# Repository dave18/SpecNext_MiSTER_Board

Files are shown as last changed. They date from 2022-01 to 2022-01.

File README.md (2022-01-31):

# SpecNext_MiSTER_Board
An extension board to provide Spectrum Next functionality to MiSTER

A MiSTer hat board MiSTER based on the offical schematics to (hopefully) allow better compatibility with the Spectrum Next core, including future updates.

It adds
* SRAM - up to 2 MB as per the next using 4 x as7c34096a-10 
* VGA out (using same resistor values from Next schematic)
* Mic/Ear port
* Audio out
* Two DB9 joystick ports
* NMI/Drive/Reset buttons
* J13 header to add physical SD Card support

Core code is based on the official MiSTer Spectrum Next Core with the following changes
* Direct VGA option - will bypass MiSTer framework and send direct video signal to VGA out (note - once this option is selected the OSD will no longer be visible over VGA until option is disabled (OSD is still visible through HDMI/DVI)
* Option to set each joystick to either MiSTer input or directly from the DSub 9 inputs
* Tape loading will automatically switch between virtual tape if loaded or from the Ear port if not
* SD Card interface will use virtual cards if loaded, else will use the J13 signals (useful if you have an Active Consult drive to plug in)

Changelog

Board V1.0 (Eagle files V3a)







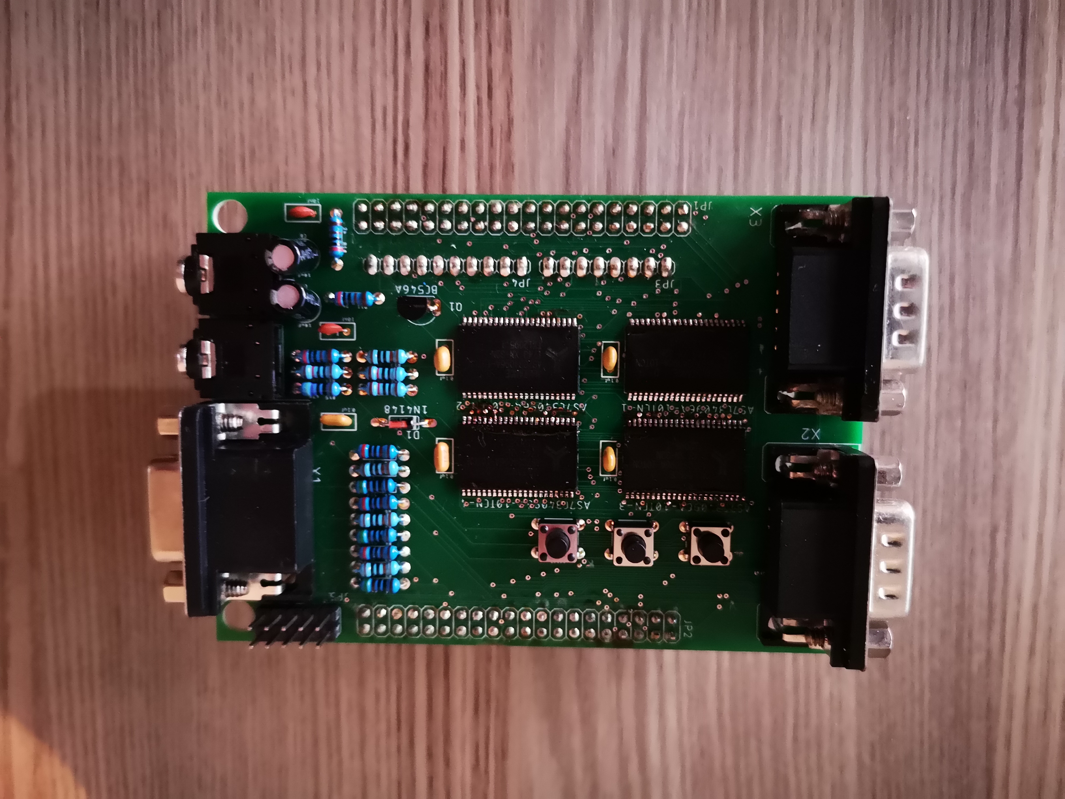
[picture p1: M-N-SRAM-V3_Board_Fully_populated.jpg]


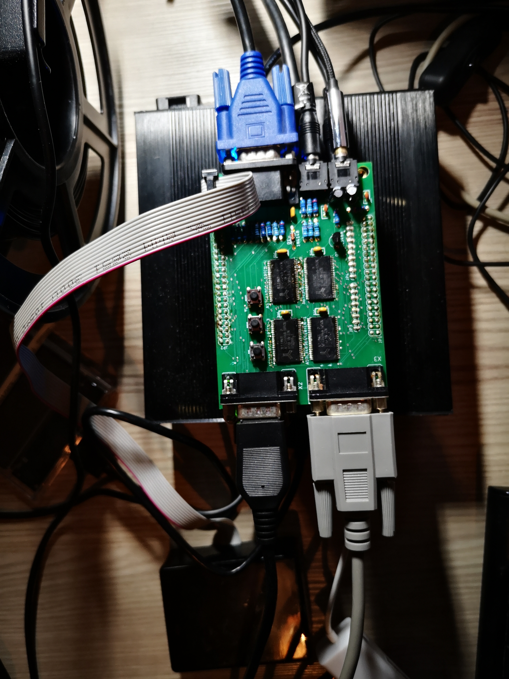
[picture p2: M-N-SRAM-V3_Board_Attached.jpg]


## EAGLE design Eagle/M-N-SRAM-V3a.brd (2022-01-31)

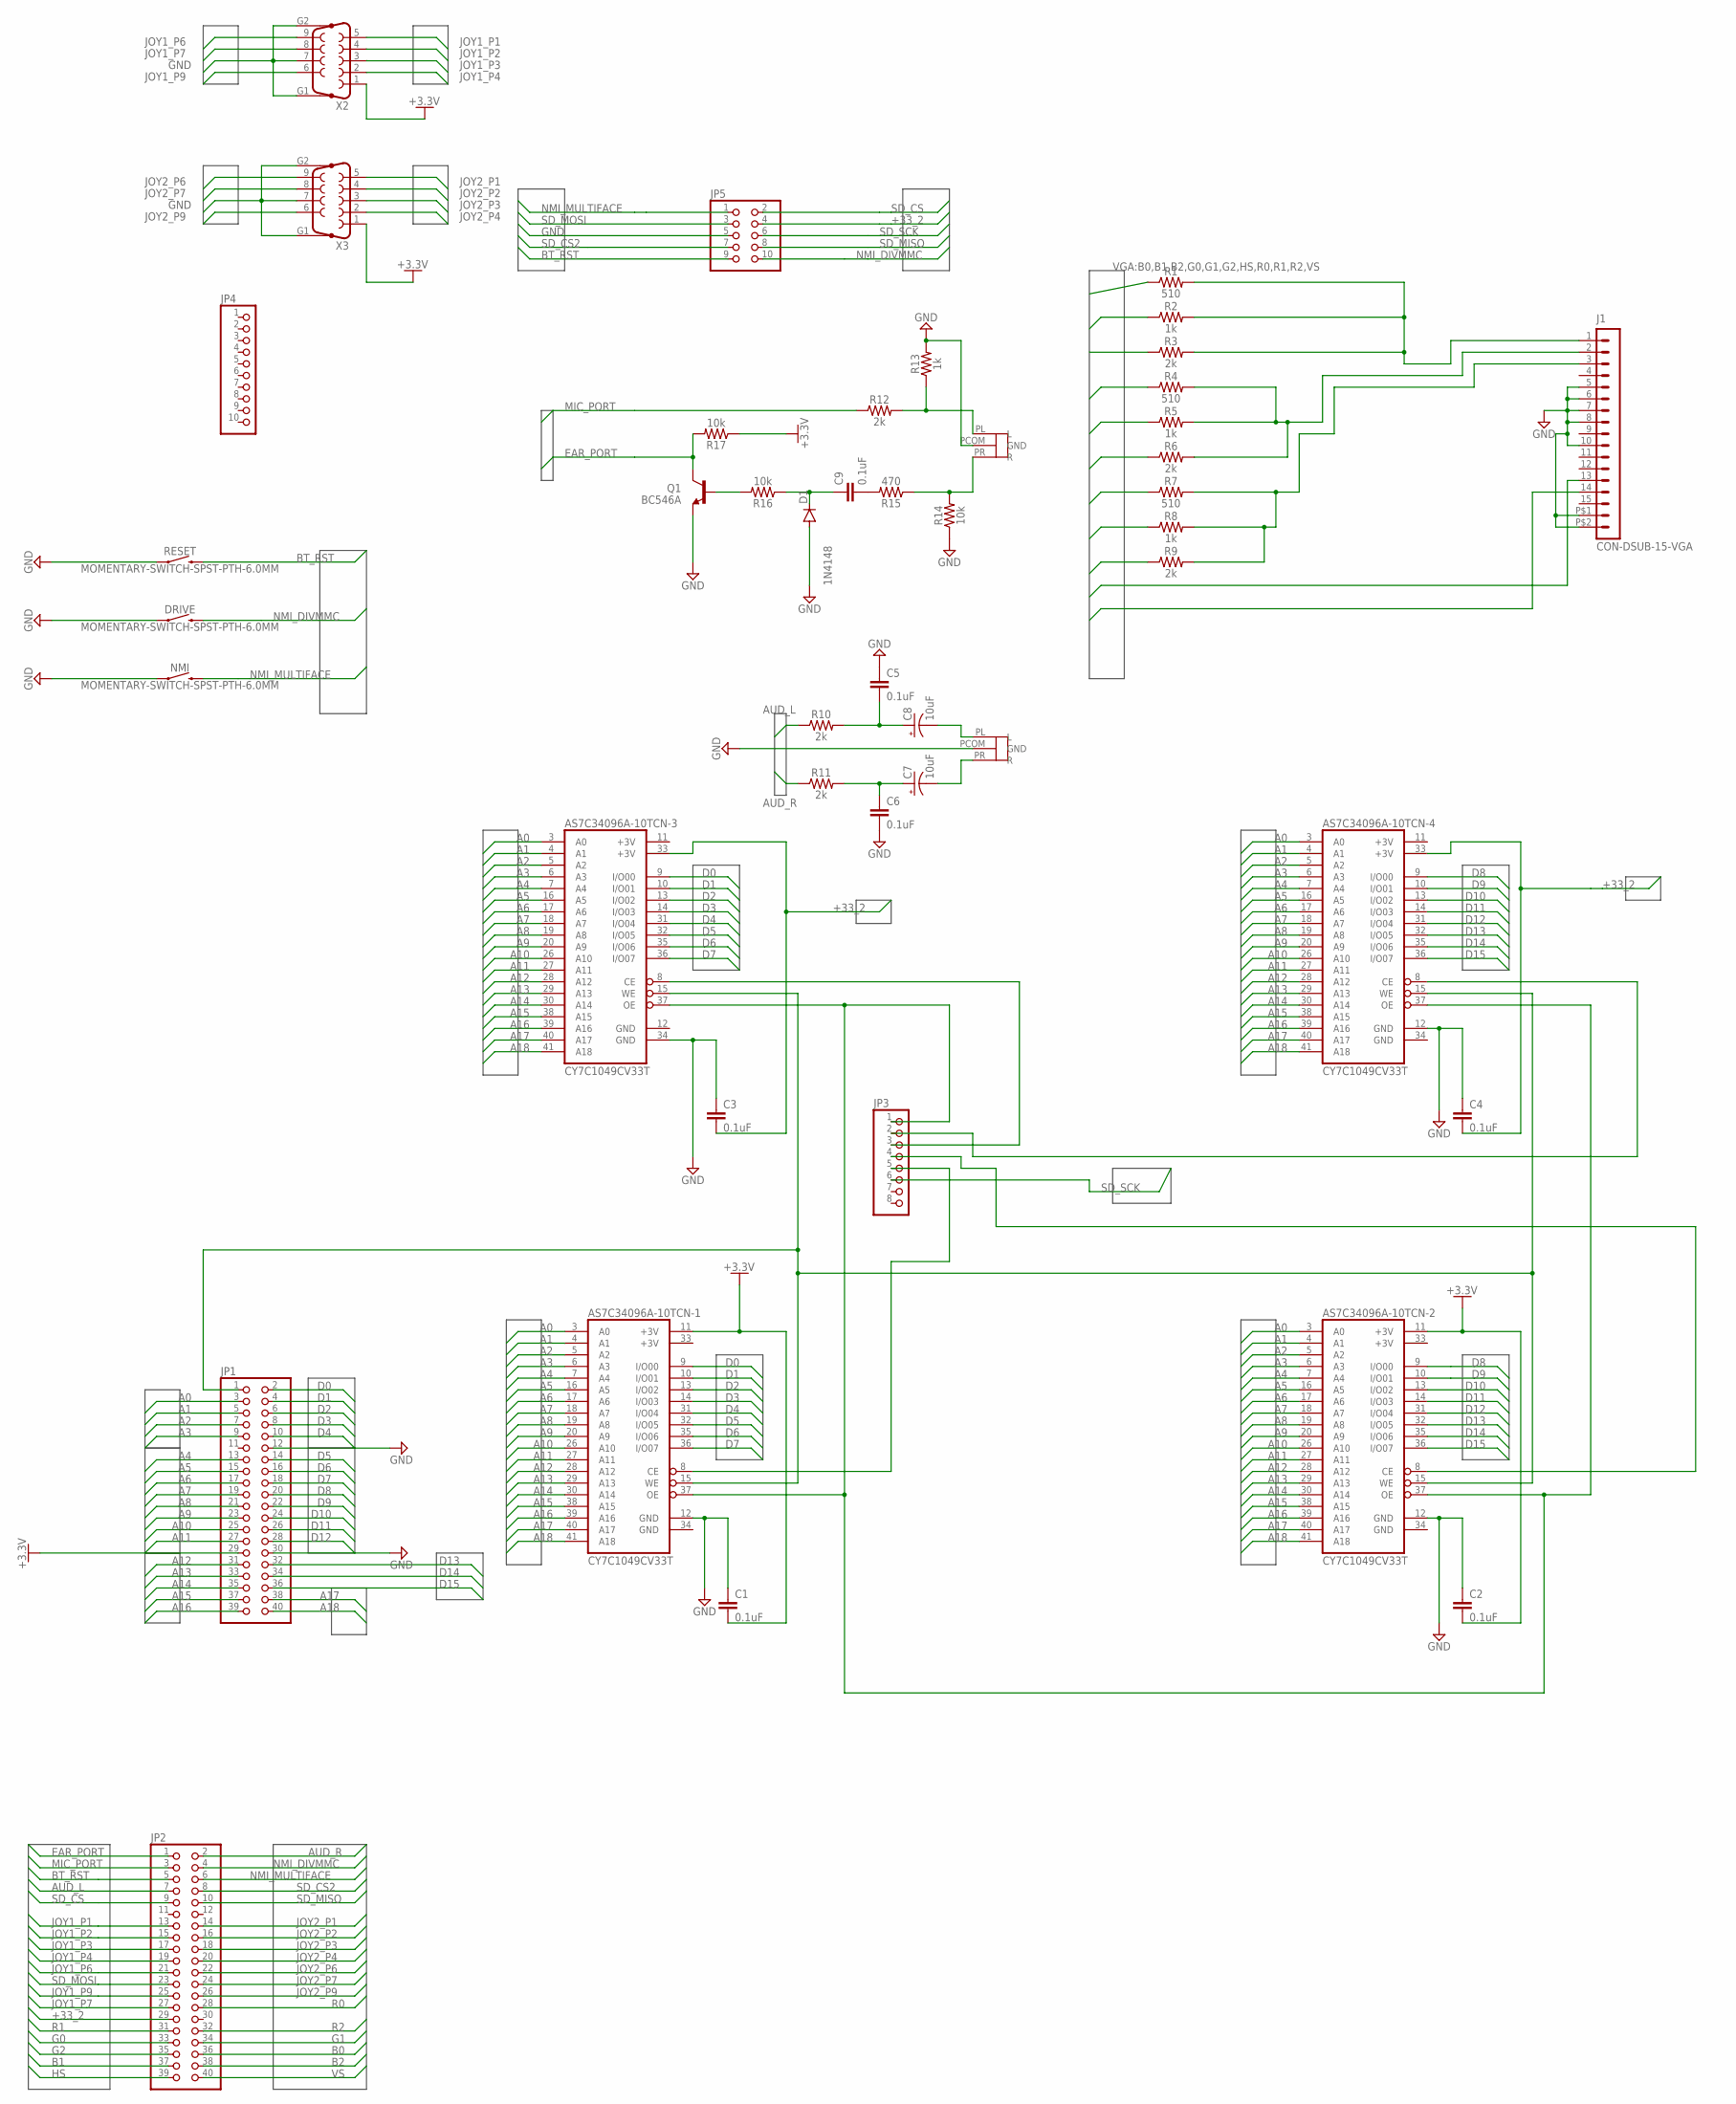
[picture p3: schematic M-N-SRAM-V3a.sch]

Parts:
AS7C34096A-10TCN-1, AS7C34096A-10TCN-2, AS7C34096A-10TCN-3, AS7C34096A-10TCN-4: CY7C1049CV33T; TSOPII-Z44
AUDIOOUT: AUDIOJACK
C1, C2, C3, C4, C5, C6, C9: 0.1uF; CAP-PTH-SMALL-KIT
C7, C8: 10uF; CPOL-RADIAL-2.5MM-5MM
D1: 1N4148; DO35-7
DRIVE: MOMENTARY-SWITCH-SPST-PTH-6.0MM; TACTILE_SWITCH_PTH_6.0MM
EAR/MIC: AUDIOJACK
J1: CON-DSUB-15-VGA; 181-015-212-171
JP1, JP2: PINHD-2X20; 2X20
JP3: PINHD-1X8; 1X08
JP4: PINHD-1X10; 1X10
JP5: PINHD-2X5; 2X05
NMI: MOMENTARY-SWITCH-SPST-PTH-6.0MM; TACTILE_SWITCH_PTH_6.0MM
Q1: BC546A; TO92-EBC
R1, R4, R7: 510; AXIAL-0.3
R2, R5, R8, R13: 1k; AXIAL-0.3
R3, R6, R9, R10, R11, R12: 2k; AXIAL-0.3
R14, R16, R17: 10k; AXIAL-0.3
R15: 470; AXIAL-0.3
RESET: MOMENTARY-SWITCH-SPST-PTH-6.0MM; TACTILE_SWITCH_PTH_6.0MM
X2, X3: F09HP

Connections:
+3.3V: AS7C34096A-10TCN-1.11 (+3V), AS7C34096A-10TCN-2.11 (+3V), C1.2, C2.2, R17.P$1 (1), X2.1, X3.1
+3V: AS7C34096A-10TCN-1.33 (+3V), AS7C34096A-10TCN-2.33 (+3V), AS7C34096A-10TCN-3.11 (+3V), AS7C34096A-10TCN-4.11 (+3V), JP1.29
+33_2: AS7C34096A-10TCN-3.33 (+3V), AS7C34096A-10TCN-4.33 (+3V), C3.2, C4.2, JP2.29, JP5.4
A0: AS7C34096A-10TCN-1.3 (A0), AS7C34096A-10TCN-2.3 (A0), AS7C34096A-10TCN-3.3 (A0), AS7C34096A-10TCN-4.3 (A0), JP1.3
A1: AS7C34096A-10TCN-1.4 (A1), AS7C34096A-10TCN-2.4 (A1), AS7C34096A-10TCN-3.4 (A1), AS7C34096A-10TCN-4.4 (A1), JP1.5
A2: AS7C34096A-10TCN-1.5 (A2), AS7C34096A-10TCN-2.5 (A2), AS7C34096A-10TCN-3.5 (A2), AS7C34096A-10TCN-4.5 (A2), JP1.7
A3: AS7C34096A-10TCN-1.6 (A3), AS7C34096A-10TCN-2.6 (A3), AS7C34096A-10TCN-3.6 (A3), AS7C34096A-10TCN-4.6 (A3), JP1.9
A4: AS7C34096A-10TCN-1.7 (A4), AS7C34096A-10TCN-2.7 (A4), AS7C34096A-10TCN-3.7 (A4), AS7C34096A-10TCN-4.7 (A4), JP1.13
A5: AS7C34096A-10TCN-1.16 (A5), AS7C34096A-10TCN-2.16 (A5), AS7C34096A-10TCN-3.16 (A5), AS7C34096A-10TCN-4.16 (A5), JP1.15
A6: AS7C34096A-10TCN-1.17 (A6), AS7C34096A-10TCN-2.17 (A6), AS7C34096A-10TCN-3.17 (A6), AS7C34096A-10TCN-4.17 (A6), JP1.17
A7: AS7C34096A-10TCN-1.18 (A7), AS7C34096A-10TCN-2.18 (A7), AS7C34096A-10TCN-3.18 (A7), AS7C34096A-10TCN-4.18 (A7), JP1.19
A8: AS7C34096A-10TCN-1.19 (A8), AS7C34096A-10TCN-2.19 (A8), AS7C34096A-10TCN-3.19 (A8), AS7C34096A-10TCN-4.19 (A8), JP1.21
A9: AS7C34096A-10TCN-1.20 (A9), AS7C34096A-10TCN-2.20 (A9), AS7C34096A-10TCN-3.20 (A9), AS7C34096A-10TCN-4.20 (A9), JP1.23
A10: AS7C34096A-10TCN-1.26 (A10), AS7C34096A-10TCN-2.26 (A10), AS7C34096A-10TCN-3.26 (A10), AS7C34096A-10TCN-4.26 (A10), JP1.25
A11: AS7C34096A-10TCN-1.27 (A11), AS7C34096A-10TCN-2.27 (A11), AS7C34096A-10TCN-3.27 (A11), AS7C34096A-10TCN-4.27 (A11), JP1.27
A12: AS7C34096A-10TCN-1.28 (A12), AS7C34096A-10TCN-2.28 (A12), AS7C34096A-10TCN-3.28 (A12), AS7C34096A-10TCN-4.28 (A12), JP1.31
A13: AS7C34096A-10TCN-1.29 (A13), AS7C34096A-10TCN-2.29 (A13), AS7C34096A-10TCN-3.29 (A13), AS7C34096A-10TCN-4.29 (A13), JP1.33
A14: AS7C34096A-10TCN-1.30 (A14), AS7C34096A-10TCN-2.30 (A14), AS7C34096A-10TCN-3.30 (A14), AS7C34096A-10TCN-4.30 (A14), JP1.35
A15: AS7C34096A-10TCN-1.38 (A15), AS7C34096A-10TCN-2.38 (A15), AS7C34096A-10TCN-3.38 (A15), AS7C34096A-10TCN-4.38 (A15), JP1.37
A16: AS7C34096A-10TCN-1.39 (A16), AS7C34096A-10TCN-2.39 (A16), AS7C34096A-10TCN-3.39 (A16), AS7C34096A-10TCN-4.39 (A16), JP1.39
A17: AS7C34096A-10TCN-1.40 (A17), AS7C34096A-10TCN-2.40 (A17), AS7C34096A-10TCN-3.40 (A17), AS7C34096A-10TCN-4.40 (A17), JP1.38
A18: AS7C34096A-10TCN-1.41 (A18), AS7C34096A-10TCN-2.41 (A18), AS7C34096A-10TCN-3.41 (A18), AS7C34096A-10TCN-4.41 (A18), JP1.40
AUDIO_OUT_L: AUDIOOUT.PL (L), C8.2 (-)
AUDIO_OUT_L1: C5.2, C8.1 (+), R10.P$2 (2)
AUDIO_OUT_R: AUDIOOUT.PR (R), C7.2 (-)
AUDIO_OUT_R1: C6.1, C7.1 (+), R11.P$2 (2)
AUD_L: JP2.7, R10.P$1 (1)
AUD_R: JP2.2, R11.P$1 (1)
B0: JP2.36, R7.P$1 (1)
B1: JP2.37, R8.P$1 (1)
B2: JP2.38, R9.P$1 (1)
BT_RST: JP2.5, JP5.9, RESET.3 (2)
D0: AS7C34096A-10TCN-1.9 (I/O00), AS7C34096A-10TCN-3.9 (I/O00), JP1.2
D1: AS7C34096A-10TCN-1.10 (I/O01), AS7C34096A-10TCN-3.10 (I/O01), JP1.4
D2: AS7C34096A-10TCN-1.13 (I/O02), AS7C34096A-10TCN-3.13 (I/O02), JP1.6
D3: AS7C34096A-10TCN-1.14 (I/O03), AS7C34096A-10TCN-3.14 (I/O03), JP1.8
D4: AS7C34096A-10TCN-1.31 (I/O04), AS7C34096A-10TCN-3.31 (I/O04), JP1.10
D5: AS7C34096A-10TCN-1.32 (I/O05), AS7C34096A-10TCN-3.32 (I/O05), JP1.14
D6: AS7C34096A-10TCN-1.35 (I/O06), AS7C34096A-10TCN-3.35 (I/O06), JP1.16
D7: AS7C34096A-10TCN-1.36 (I/O07), AS7C34096A-10TCN-3.36 (I/O07), JP1.18
D8: AS7C34096A-10TCN-2.9 (I/O00), AS7C34096A-10TCN-4.9 (I/O00), JP1.20
D9: AS7C34096A-10TCN-2.10 (I/O01), AS7C34096A-10TCN-4.10 (I/O01), JP1.22
D10: AS7C34096A-10TCN-2.13 (I/O02), AS7C34096A-10TCN-4.13 (I/O02), JP1.24
D11: AS7C34096A-10TCN-2.14 (I/O03), AS7C34096A-10TCN-4.14 (I/O03), JP1.26
D12: AS7C34096A-10TCN-2.31 (I/O04), AS7C34096A-10TCN-4.31 (I/O04), JP1.28
D13: AS7C34096A-10TCN-2.32 (I/O05), AS7C34096A-10TCN-4.32 (I/O05), JP1.32
D14: AS7C34096A-10TCN-2.35 (I/O06), AS7C34096A-10TCN-4.35 (I/O06), JP1.34
D15: AS7C34096A-10TCN-2.36 (I/O07), AS7C34096A-10TCN-4.36 (I/O07), JP1.36
EAR_PORT: JP2.1, Q1.C, R17.P$2 (2)
G0: JP2.33, R4.P$1 (1)
G1: JP2.34, R5.P$1 (1)
G2: JP2.35, R6.P$1 (1)
GND: AS7C34096A-10TCN-1.12 (GND), AS7C34096A-10TCN-1.34 (GND), AS7C34096A-10TCN-2.12 (GND), AS7C34096A-10TCN-2.34 (GND), AS7C34096A-10TCN-3.12 (GND), AS7C34096A-10TCN-3.34 (GND), AS7C34096A-10TCN-4.12 (GND), AS7C34096A-10TCN-4.34 (GND), AUDIOOUT.PCOM (GND), C1.1, C2.1, C3.1, C4.1, C5.1, C6.2, D1.A, DRIVE.1, EAR/MIC.PCOM (GND), J1.5, J1.6, J1.7, J1.8, J1.10, J1.P$1 (16), J1.P$2 (17), JP1.12, JP1.30, JP5.5, NMI.1, Q1.E, R13.P$2 (2), R14.P$1 (1), RESET.1, X2.7, X2.G1, X2.G2, X3.7, X3.G1, X3.G2
HS: J1.13, JP2.39
JOY1_P1: JP2.13, X2.5
JOY1_P2: JP2.15, X2.4
JOY1_P3: JP2.17, X2.3
JOY1_P4: JP2.19, X2.2
JOY1_P6: JP2.21, X2.9
JOY1_P7: JP2.27, X2.8
JOY1_P9: JP2.25, X2.6
JOY2_P1: JP2.14, X3.5
JOY2_P2: JP2.16, X3.4
JOY2_P3: JP2.18, X3.3
JOY2_P4: JP2.20, X3.2
JOY2_P6: JP2.22, X3.9
JOY2_P7: JP2.24, X3.8
JOY2_P9: JP2.26, X3.6
MIC_PORT: JP2.3, R12.P$1 (1)
unnamed: EAR/MIC.PL (L), R12.P$2 (2), R13.P$1 (1)
unnamed: C9.2, R15.P$2 (2)
unnamed: EAR/MIC.PR (R), R14.P$2 (2), R15.P$1 (1)
unnamed: C9.1, D1.C, R16.P$1 (1)
unnamed: Q1.B, R16.P$2 (2)
NMI_DIVMMC: DRIVE.3 (2), JP2.4, JP5.10
NMI_MULTIFACE: JP2.6, JP5.1, NMI.3 (2)
R0: JP2.28, R1.P$1 (1)
R1: JP2.31, R2.P$1 (1)
R2: JP2.32, R3.P$1 (1)
RAM_CE1: AS7C34096A-10TCN-1.8 (CE), JP3.5
RAM_CE2: AS7C34096A-10TCN-2.8 (CE), JP3.4
RAM_CE3: AS7C34096A-10TCN-3.8 (CE), JP3.3
RAM_CE4: AS7C34096A-10TCN-4.8 (CE), JP3.2
RAM_OE: AS7C34096A-10TCN-1.37 (OE), AS7C34096A-10TCN-2.37 (OE), AS7C34096A-10TCN-3.37 (OE), AS7C34096A-10TCN-4.37 (OE), JP3.1
RAM_WE: AS7C34096A-10TCN-1.15 (WE), AS7C34096A-10TCN-2.15 (WE), AS7C34096A-10TCN-3.15 (WE), AS7C34096A-10TCN-4.15 (WE), JP1.1
SD_CS: JP2.9, JP5.2
SD_CS2: JP2.8, JP5.7
SD_MISO: JP2.10, JP5.8
SD_MOSI: JP2.23, JP5.3
SD_SCK: JP3.6, JP5.6
VGA_BLUE: J1.3, R7.P$2 (2), R8.P$2 (2), R9.P$2 (2)
VGA_GREEN: J1.2, R4.P$2 (2), R5.P$2 (2), R6.P$2 (2)
VGA_RED: J1.1, R1.P$2 (2), R2.P$2 (2), R3.P$2 (2)
VS: J1.14, JP2.40

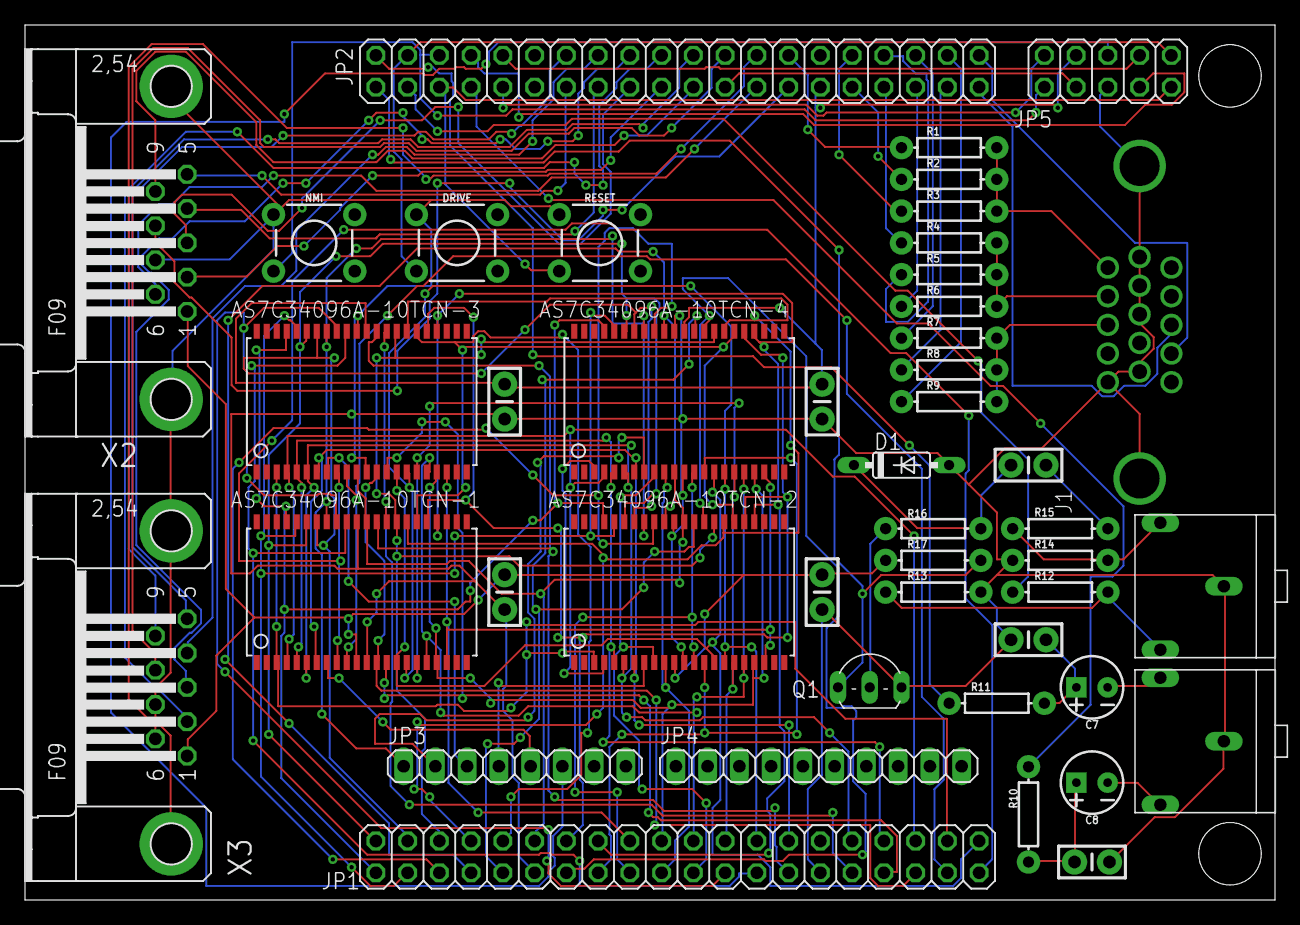
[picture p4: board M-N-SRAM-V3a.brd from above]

Board: 2 copper layers, 100.0 x 70.0 mm, 45 parts (0 on the bottom side), 94 nets.

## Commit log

2021-03-24 Add v8 Eagle files
    V8 Eagle files relate to official V2.0 board
    [M-N-SRAM-V8.brd, M-N-SRAM-V8.sch]
2021-03-24 Schematic Correction
    [M-N-SRAM-V8.brd, M-N-SRAM-V8.sch]

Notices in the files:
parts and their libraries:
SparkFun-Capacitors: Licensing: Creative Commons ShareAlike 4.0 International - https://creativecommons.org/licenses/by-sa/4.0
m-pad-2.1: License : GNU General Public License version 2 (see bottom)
